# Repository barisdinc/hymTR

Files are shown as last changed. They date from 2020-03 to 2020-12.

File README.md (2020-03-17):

# hymTR
APRS Tracker
Arduino Uno ile calisan bir APRS tracker projesidir. 
Temel oalrak asagidaki ozelliklere sahiptir :
- Herhangibir arduino ile calisir
- Telsize hoparlor arayuzunden baglanir
- 4 bitlik bir Direnc iskelesi (resistor ladder) DAC ile calisir (16 seviye)
- Asagidaki verileri GPS den okur
  - Zaman
  - Pozisyon
  - Hiz/yonlenme vb
  - Uydu sayisi
  - Fix durumu
- Smart beacon ozelligi ile hiz ile orantili olarak gonderme sikligini degistirir
- Verileri EEPROM'da saklar
- PC Yazilimi ile tum ayarlari degistirilebilir

Eklenmesi planlanan ozellikler :
- APRS dinleme ozelligi
- Dorji radyolari yonetebilme ozelligi
- Display ekelenebilir

PC Yonetim arayuzu programi "hymTR Ayar Programi" ayri bir repository icindedir.

Donanim detaylari icin <A HREF="https://github.com/barisdinc/hymTR/blob/master/Hardware/README.md">Donanim Sayfasi'na bakabilirsiniz</A>

Ocak 2020

Proje destekcileri :
--------------------
- TA2GY Cem Karagoz
- TA6AEU Emre Keles

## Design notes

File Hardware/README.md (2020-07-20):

hymTRacker Donanim Genel gorunumu

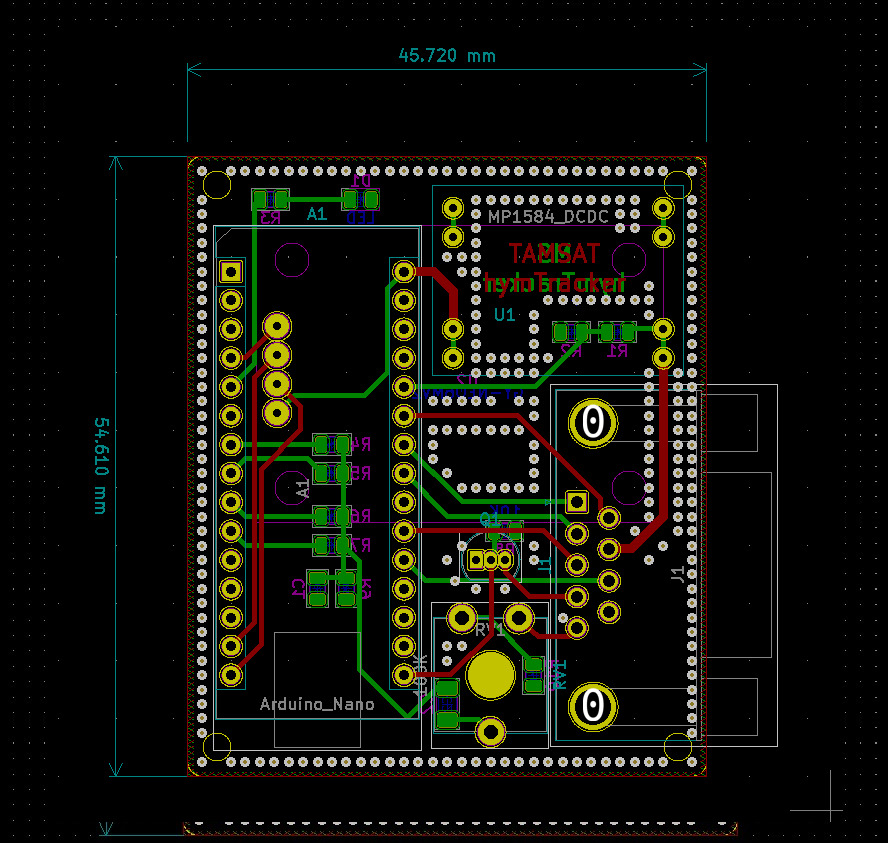
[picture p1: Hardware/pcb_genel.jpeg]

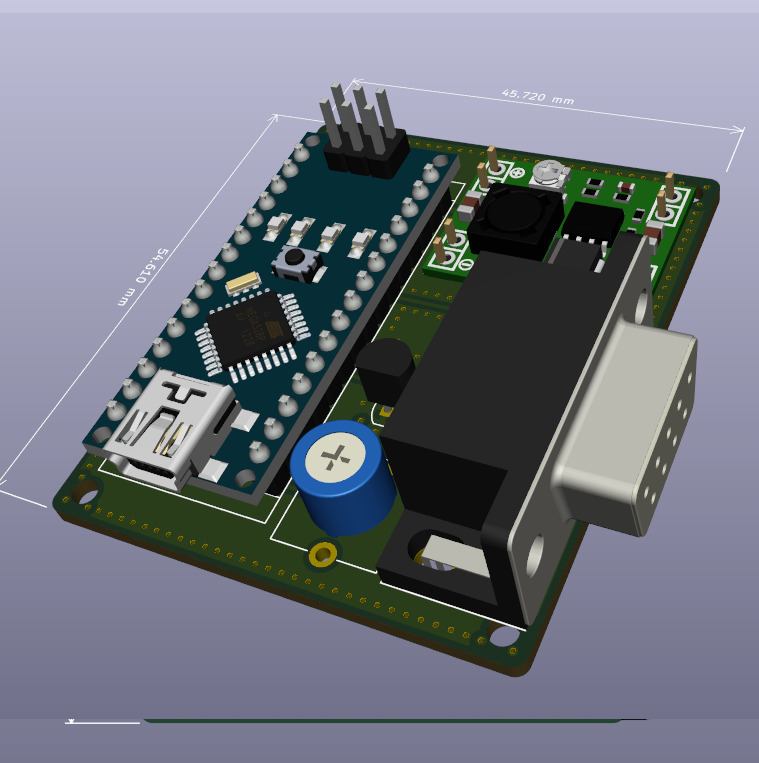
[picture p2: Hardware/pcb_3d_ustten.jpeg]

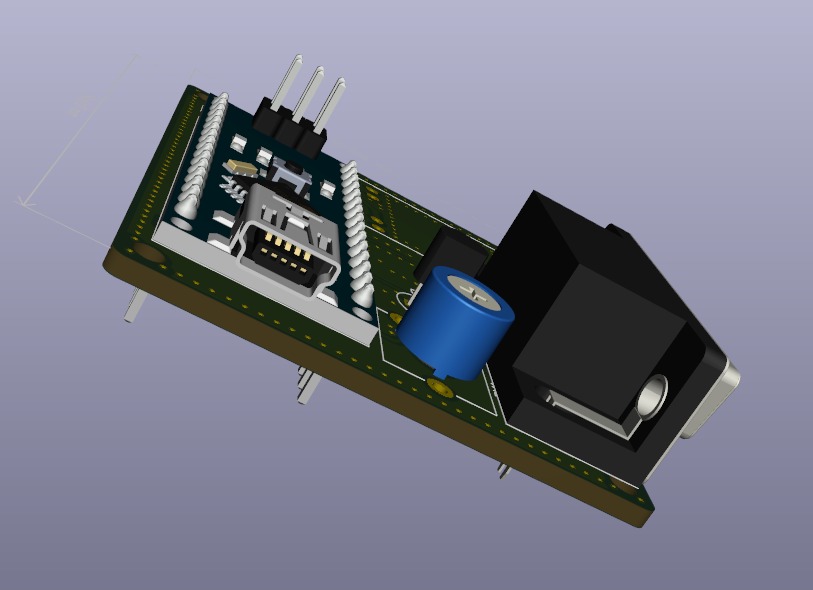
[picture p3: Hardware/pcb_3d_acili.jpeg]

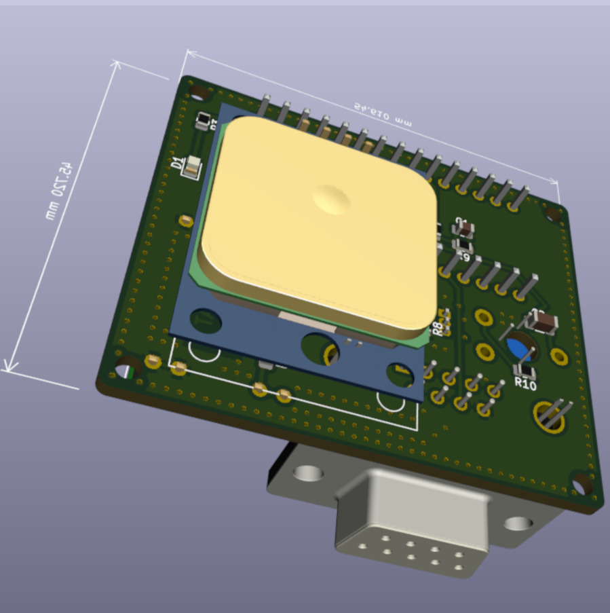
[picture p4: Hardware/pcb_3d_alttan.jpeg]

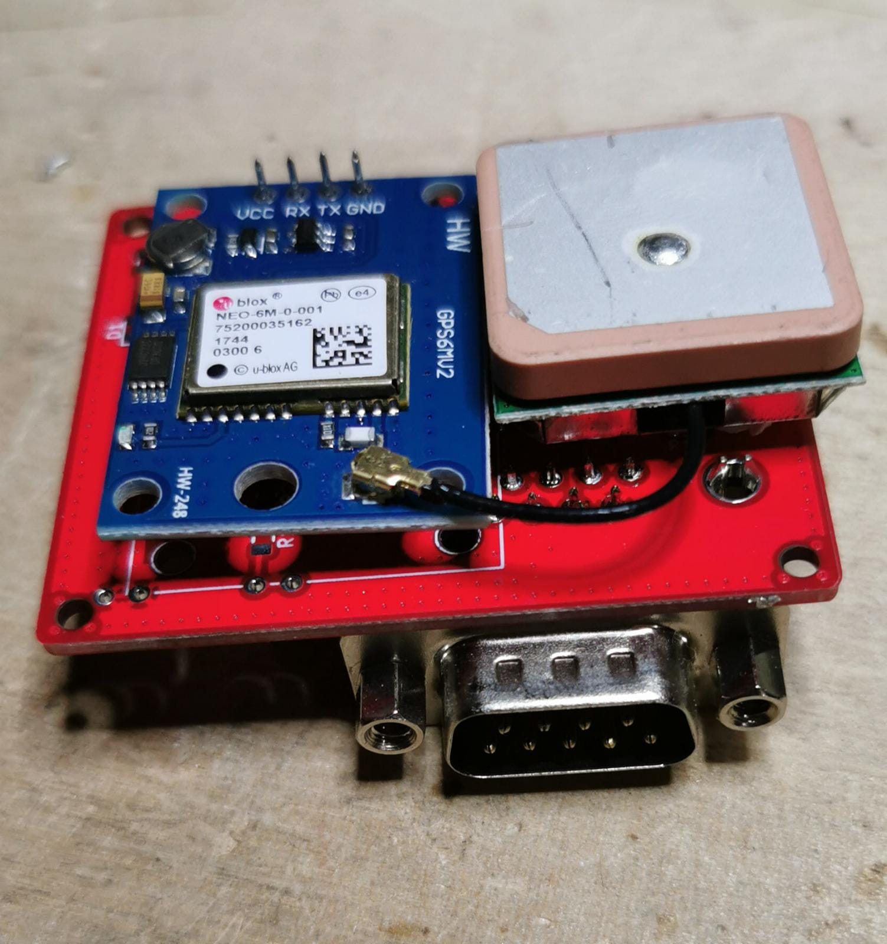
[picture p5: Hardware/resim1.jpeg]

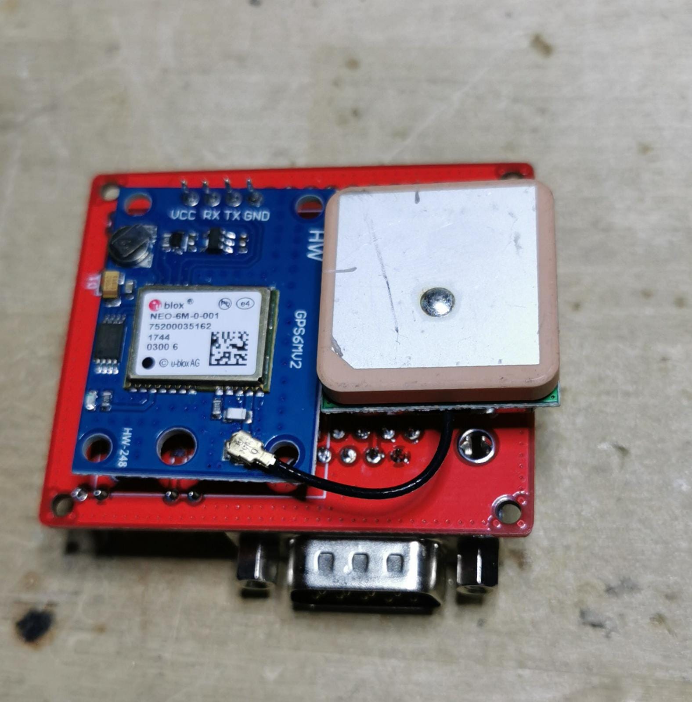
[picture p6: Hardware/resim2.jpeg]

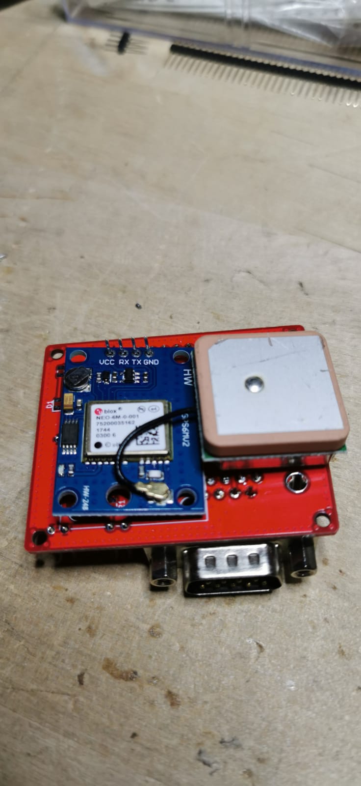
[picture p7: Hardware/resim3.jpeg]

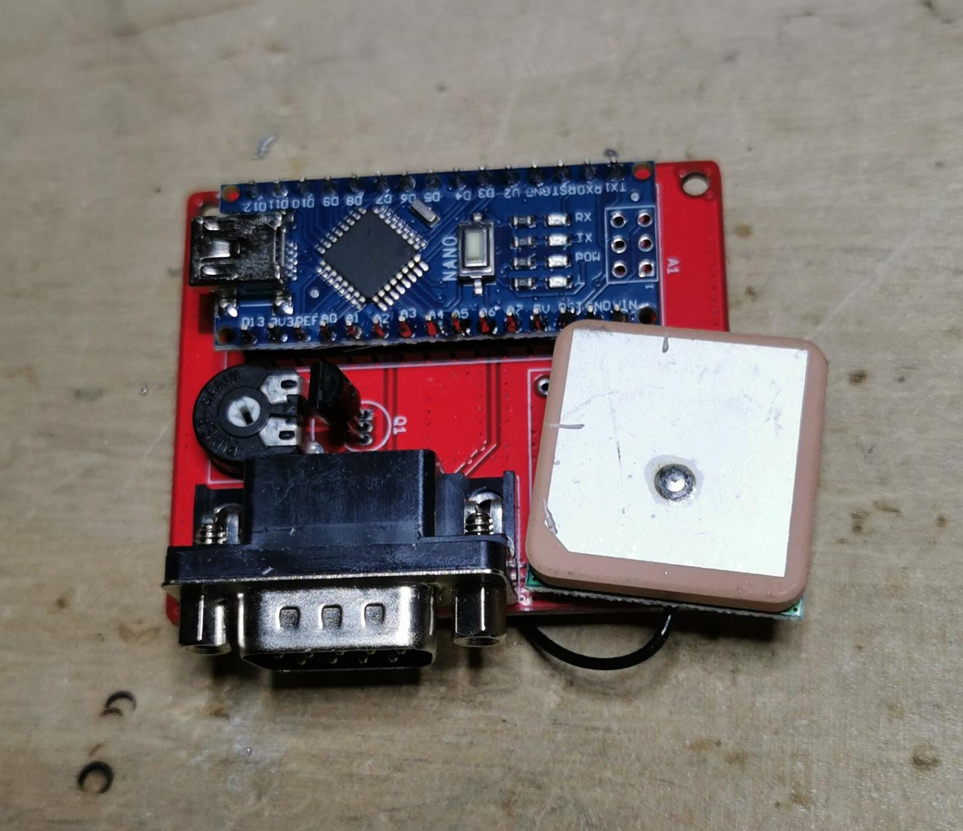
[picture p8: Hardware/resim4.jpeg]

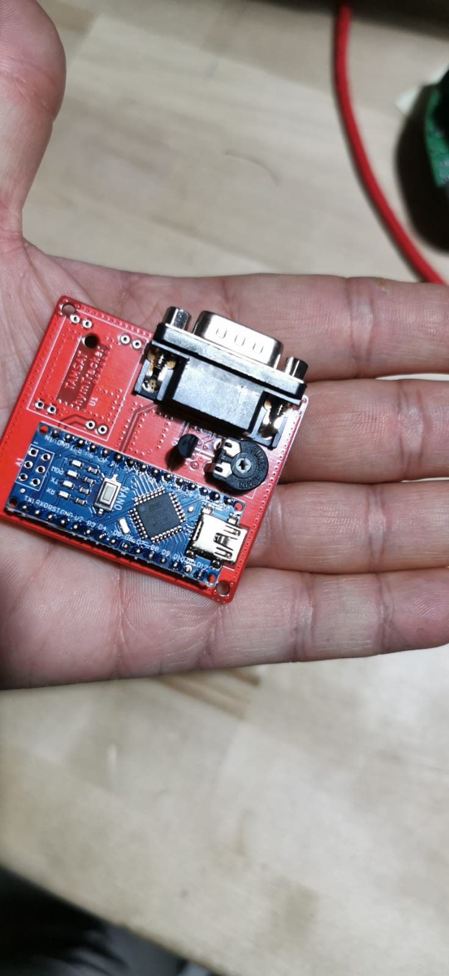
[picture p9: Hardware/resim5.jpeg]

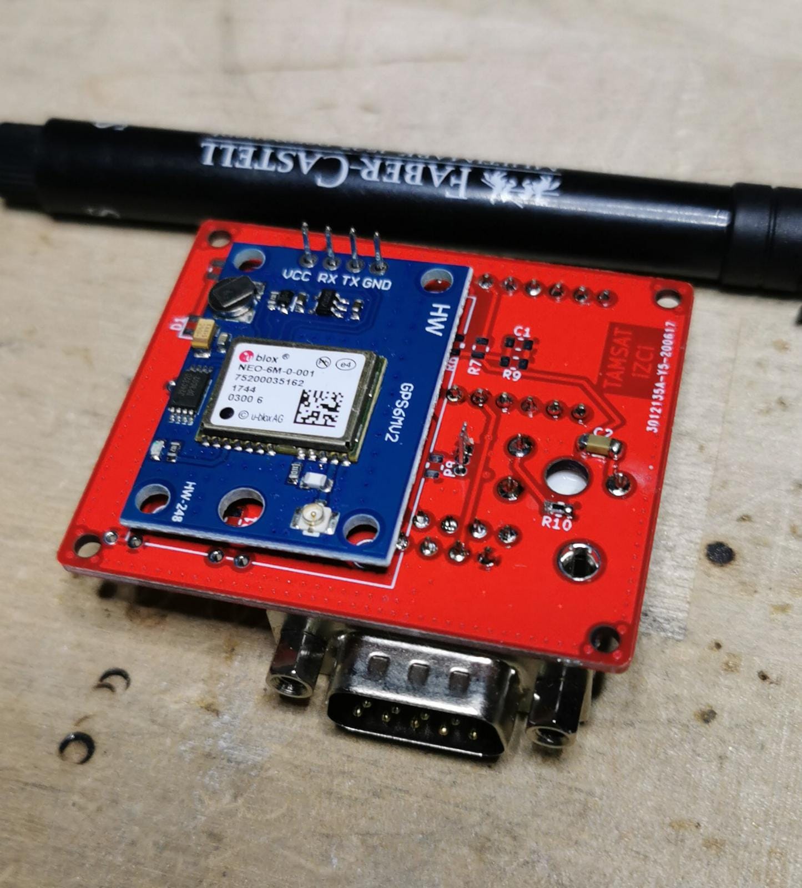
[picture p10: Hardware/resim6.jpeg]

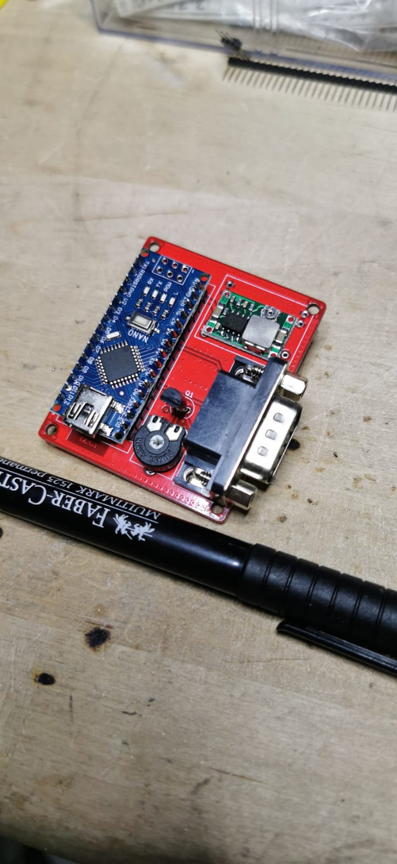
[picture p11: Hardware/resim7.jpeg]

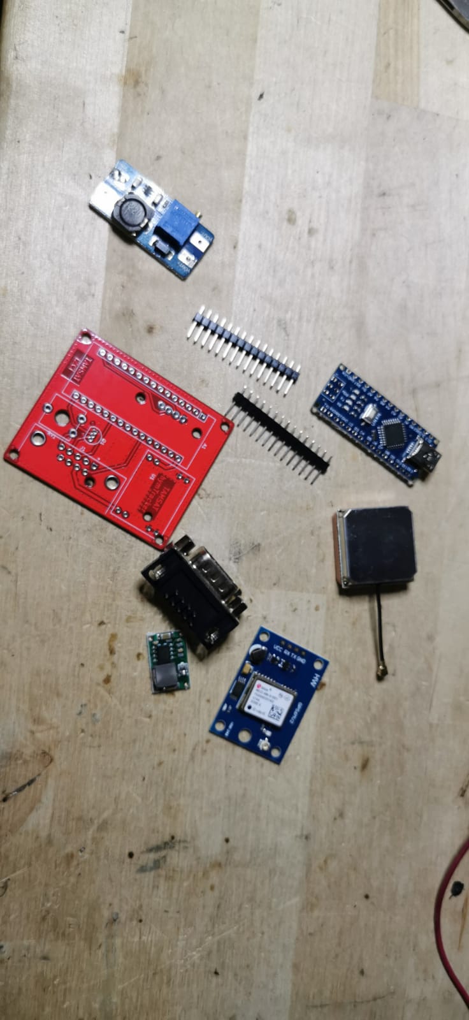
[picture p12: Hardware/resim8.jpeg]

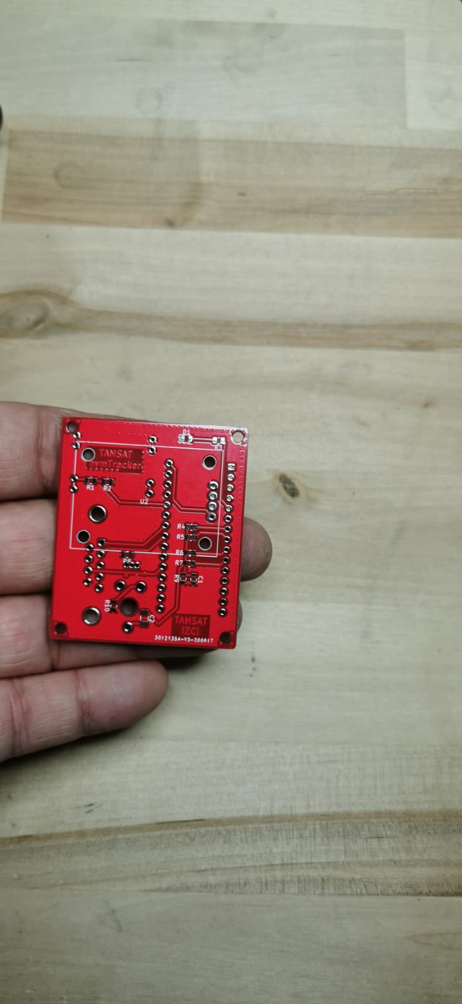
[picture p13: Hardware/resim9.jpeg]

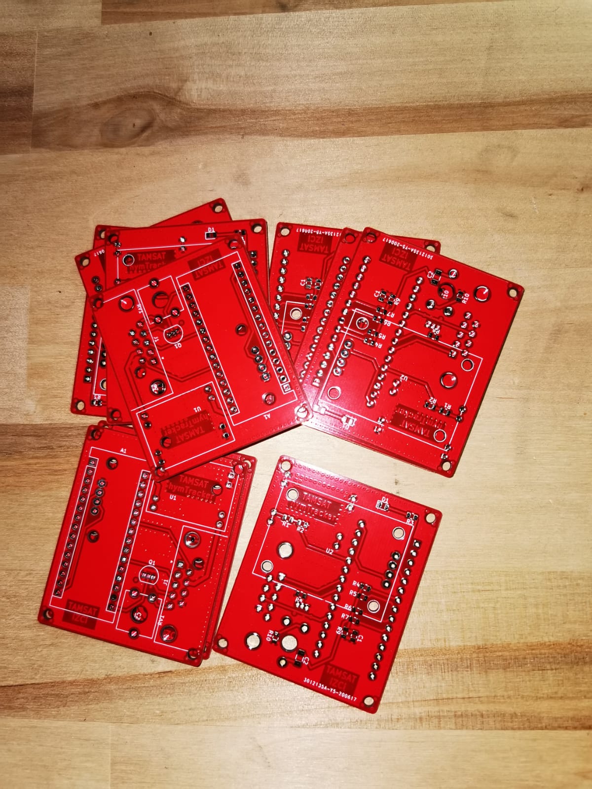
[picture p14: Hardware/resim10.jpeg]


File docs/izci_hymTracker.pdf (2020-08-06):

Önce biraz tarihte yolculuk yapalım….
Yıllar yıllar önce telsiz üzerinden bilgisayar verisi gönderebileceğimi keşfettiğimde dünyalar benim olmuştu. 90’lı yıllarda telsizlerimize bağladığımız ANTRAK HF/VHF modemleri ile hem HF’de (300 baud) hem de VHF’de (1200 baud) pekçok sayısal haberleşmeyi başarmıştık. Yavaştı ama çok da iş görüyordu.
90’lı yıllarda ülkemize henüz internet yeni gelmişken ve kimseciklerin evinde internet yokken, hatta adını bile kimse bilmezken biz bir grup amatör telsizci (ki ben evime telefon bağlatamadığım ve telefon sırasının da 6 aydan önce olmamacı da abir yana) telsizlerimize bağladığımız modemler ve AX25 protokolü ile birbirimizle haberleşiyorduk.
Uzun bir süre ÖDTÜ ve Ankara Üniversitesime kurduğumuz AMPR (Amateur Packet Radio Network) üzerinden internete de bağlanıyorduk.
Bu konular ve o yıllardaki deneyimlerimizle ilgili olarak şu linkleri ziyaret etmenizi öneririm ;
- Telsiz Veri İletişimi (Bölüm 1) : https://www.youtube.com/watch?v=VK49hlQoCso
- Telsiz Veri İletişimi (Bölüm 2) : https://www.youtube.com/watch?v=RfGFjVR-Ls0&t=9s
- Telsiz Veri İletişimi Sunum Dokümanı : https://github.com/barisdinc/Sunumlar/raw/master/ANTRAK_AX25_APRS_v1.pdf
- Linux ve AX25 : https://github.com/barisdinc/Sunumlar/raw/master/Packet-Radio-ve-Linux %20(2).ppt (https://github.com/barisdinc/Sunumlar/raw/master/Packet-Radio-ve-Linux%20(2).ppt)

Ardından internetin yaygınlaşması, her eve kolayca telefon (dialup) ve dahası ADSL, WIFI gibi hizmetlerin gelmesi, cep telefonlarındaki akıl almaz ilerleme sonrasında bu telsiz üzerinden veri haberleşmesi konusuna biraz uzak kalmıştım.
Taa ki askeri bir projede kullanabileceğim bir altlık protokolü arayışına girene dek, eski dost yine beni kurtarmıştı “AX25”…. Gerçi küp uydu haberleşme sistemlerinde AX25 ile haşır neşir oluyorduk ama temel kullanımdan öteye de geçemiyorduk.
Dokümanları okurken, hep bildiğim ucundan kullandığım ama bir yandan da kendimce “ARAÇ TAKİP SİSTEMİ” muamelesi çektiğim APRS (Amateur Paclet Reporting System) sistemini inceleyince gördüm ki zamanında (1980’li yıllar) askeri gemilerin haberleşmesi ve hem koordinat paylaşımı hem de taktik deniz resmi oluşturulması için bu protokolün içinde yok yok. O zamanlar bunu Commodore 64 bilgisayar üzerinde çalıştırıyor ve gemi telsizlerine bağlayarak kullanıyorlarmış.
APRS ile ilgili olarak spesifikasyonların anlatıldığı http://www.aprs.org/doc/APRS101.PDF dokümanı okuyabileceğiniz en güzel doküman bence.

Nasıl başladık…….
Bu arada bir Amatör Telsizci APRS grubu olan “APRS Türkiye” grubuna dahil olmuştum ve Türkiye’deki APRS çalışmalarını uzaktan takip etmeye çalışıyordum. Birgün bu platformun yöneticilerinden Emre Keleş (TA6AEU) ile yaptığımız uzun bir telefon görüşmesinde “biz bir tracker yapamazmıyız?” sorusu herşeyin başlangıcı oldu. Yaparız yapmasına da, öyle herhangibir tracker yapmak bize yakışmazdı, o yüzden hemen “yaparız” demedim, kafamın içinde uzun vadeli bir plan yaptım (bu görüşme sanırım 1 yıl kadar önceydi).

Önce yapılmış olan projeleri incelemeye başladım, sonra nasıl bir donanım olmalı konusuna yoğunlaştım. Hem basit olmalıydı, herkes kolayca yapabilmeli ve kullanabilmeliydi hem de biz eözgün olmalıydı.

Örnekleri inceleyince gördüm ki donanımda özgünlüğü sağlamak zor olacaktı,;
- Herkesin kolayca erişebileceği ve programlayabileceği bir arduino
- En ucuzundan bir GPS alıcısı
- Basit bir regülatör yada buck çevirici
- Konnektörler ve ledler

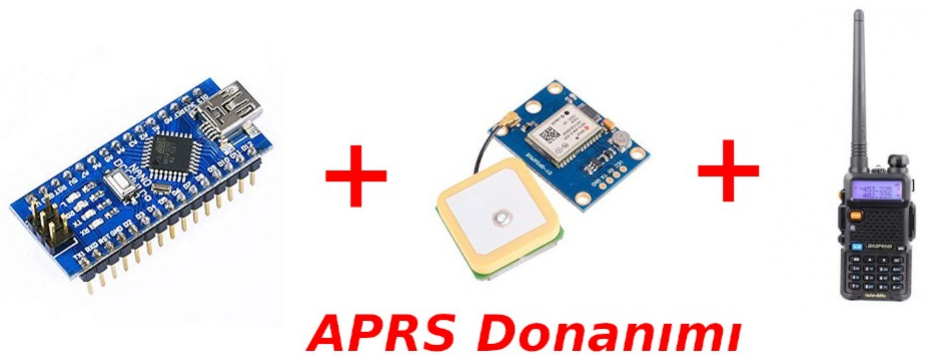
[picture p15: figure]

Ama yazılım konusunda özgün birşeyler oluşturabilirdik. İşte böyle başladı “İZCİ hymTracker” projesi.

Nasıl oluyor da oluyor…..
Sanırım kolay olan tarafı donanım olacağı için donanımdan başlamak daha doğru olacak. Amacımız 1200 ve 2200 Hz’lik ses tonları üretmek ve bunlara ‘0’ ile ‘1’ sayısal değerlerini eşlemek (bunlara mark ve space de denir). Yani işlemcimizden (arduino Nano için ATMEL mega328p) çıkacak veriyi 2 tondaki ses sinyallerine çevirmeliyiz.

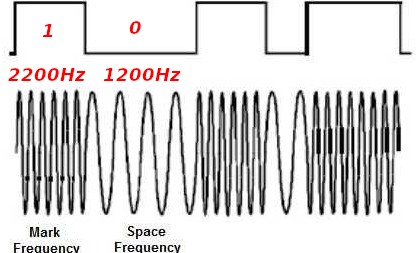
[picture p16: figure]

Sayısal verinin analog bir forma dönüştürülmesine Analog-to-Digital Conversion (ADC) diyoruz ve bunu ya bir ADC çipi ile ya da en basinten Resistor-Ladder dediğimiz birkaç direnç ile yapabiliyoruz. En ucuz ve kolay yolu (işlemcimizde de yeterince boş bacağımız olduğu için) resistor ladder (direnç merdiveni) olduğundan 4-bit’lik (4 tane işlemci sayısal bacağı kullanan) devreyi kullanmayı tercih ettim.

Aşağıda şemamızın bu bölümünü görebilirsiniz;

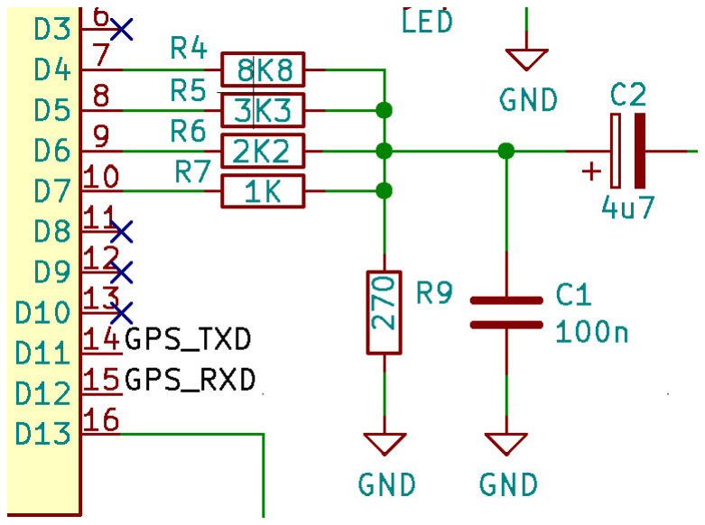
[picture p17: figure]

İşlemcimizin D4,D5,D6 ve D7 bacaklarından HIGH (3V3) verdiğimizde hesaplanmış olan dirençler üzerinden toplanarak (1K, 2K2, 3K3 ve 8K8) bir voltaş değeri oluşturulur. Bu işlemci kontrolünde çok hızlı yapabilirisek (1200 Hz için saniyede yaklaşık 1200 kez ve 2200 Hz için saniyede 2200 kez, ya da yazının yazılım bölümünde anlatacağım küçük bir trik ile daha basit bir şekilde) 4 bitlik yani 14 seviyeye sahip bir sayısal analog çevirici yapmış oluruz. Oluşan sinyal aşağıdakine benzer birşey olacaktır;

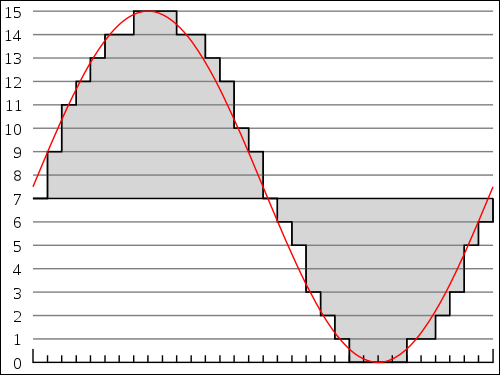
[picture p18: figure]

Aslında APRS Tracker’ımızın en can alıcı noktası yani modemi de sadece bu 4 dirençten oluşuyor. Kalan kısmında 2 bacak üzerinden (RX ve TX) bağlı olan GPS’imiz, PTT tetiklemesi için bir transistörümüz, TX anında yanan bir LED2imi, 9 pin DSUB-9 konnektörümüz ve sistemin 3-30 volt aralığında çalışmasını sağlayan BUCK converterimiz var. BU sayede sistem aşağıdaki gibi beslemelerle hiçbir değişiklik ya da düzenleme yapılmaksızın kullanılabiliniyor;
- Sistem 3V7 lityum pil
- 5V power bank
- 9V kare pil
- 12V araba aküsü
- 19V laptop pili
- 24V kamyon aküsü, vb.
Şemamız aşağıdaki gibidir;

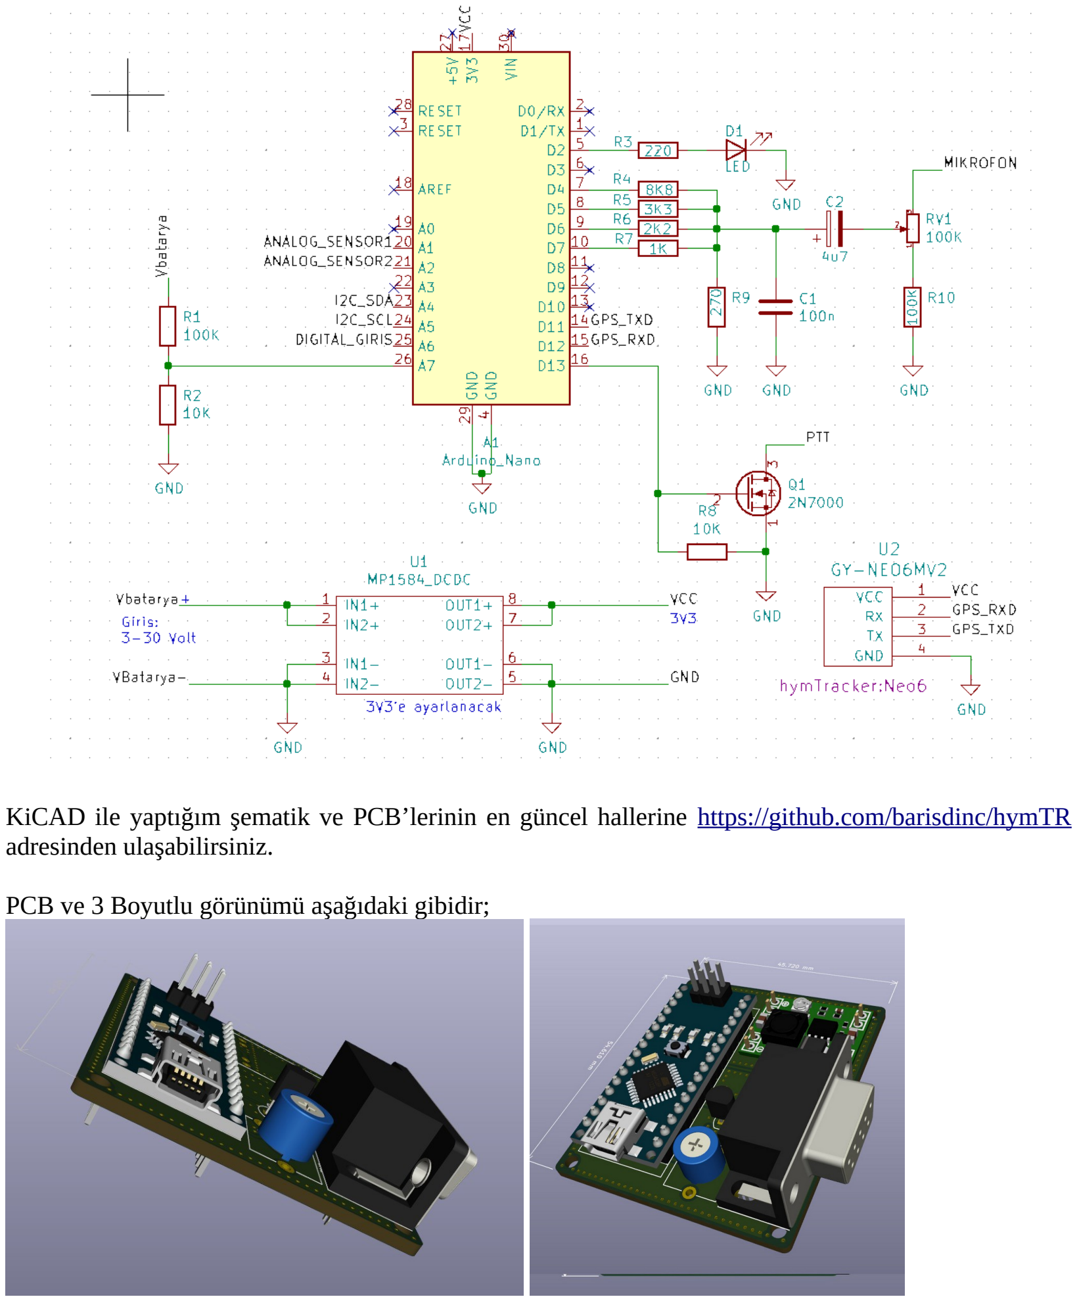
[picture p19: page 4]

KiCAD ile yaptığım şematik ve PCB’lerinin en güncel hallerine https://github.com/barisdinc/hymTR adresinden ulaşabilirsiniz.

PCB ve 3 Boyutlu görünümü aşağıdaki gibidir;

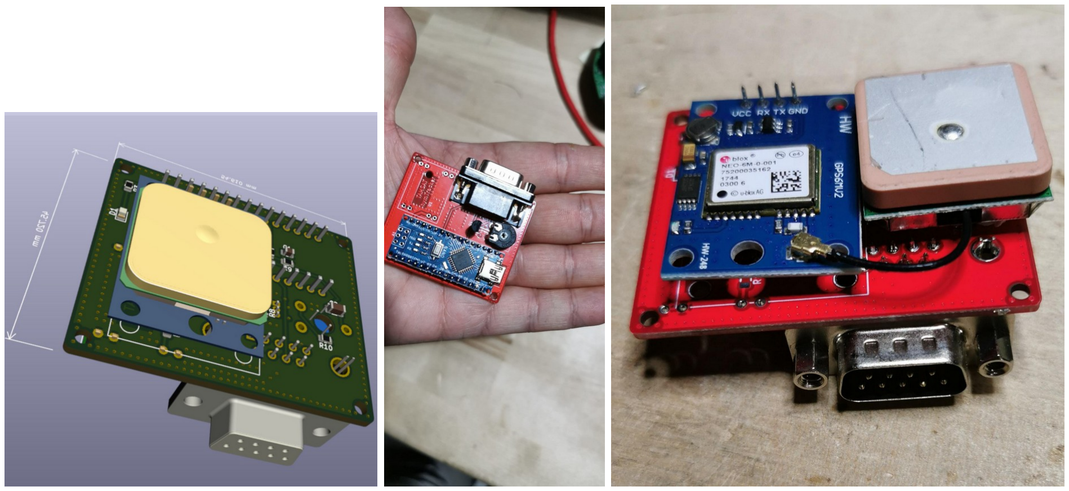
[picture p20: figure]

Donanım istediğimiz boyutlarda ve özelliklerde, küçük bir kutu içerisinde aracımızın herhangi bir yerine koyabiliriz.

Peki ya işlemci üzerindeki yazılım !!!!….

İşlemci üzerindeki yazılım yapması gerekenleri şu şekilde belirlemiştim;
- 1200Hz ve 2200Hz sinyallerini direnç-merdiveni DAC devresini kullanarak oluşturacak,
- AX25 dizilimine uygun olarak APRS paketleri oluşturabilecek,
- GPS den koordinat ve zaman bilgisi okuyabilecek,
- GPS verisini APRS verisine çevirebilecek,
- Batarya/Akü durumunu ölçebilecek ve bunu APRS verisine ekleyebilecek,
- Harici sensörlerden (analog ve sayısal) verş okuyarak bunları APRS verisine ekleyebilecek
https://github.com/barisdinc/hymTR/blob/master/src/hymTR.ino | adresinden | erişebileceiğiniz
programın genel özellikleri aşağıdaki gibi açıklanabilir;

LibAPRS_Tracker kütüphanesini kullanır. Bu kütüphane bu proje kapsamında hazırlanmış ve Arduino IDE kütüphanesi olarak kaydettirilmiş bir kütüphane olup, Ardu,ino IDE’sindeki (bugün için) tek
APRS | Tracker | kütüphanesidir | (https://www.arduinolibraries.info/libraries/lib-aprs_tracker,
https://github.com/barisdinc/LibAPRS_Tracker,https://platformio.org/lib/show/7001/LibAPRS_Tracker)

Kütüphanenin görevi AX25 paketini oluşturmak ve APRS için gerekli ses sinyallerini üretmektir. Bu kütüphaneyi kullanarak ve sadece birkaç satır kod yazarak aşağıdaki gibi bir APRS programı çalıştırabilirsiniz;

/*
* This is a very simple usage for LibAPRS_Tracker
*
* Author : Baris DINC (TA7W/OH2UDS)
*
*/
#include <LibAPRS_Tracker.h>

void setup()
{
APRS_init();
char myCALL[] = "TA7W";
char Lat[] = "2134.00N";
char Lon[] = "01234.00E";
APRS_setCallsign(myCALL, 9); APRS_setLat(Lat);
APRS_setLon(Lon);
}
void loop() {
char comment []= "TAMSAT hymTR APRS Tracker Test"; APRS_sendLoc(comment, strlen(comment));
while(bitRead(PORTB,5)); //Wait for transmission to be completed delay(10000); }

Bunun ayarlarını nasıl yapacağız ?….

Herkesin arduino programını açıp çağrı işaretini değiştirmesini ya da sembolünü ayarlamasını bekleyemezdik bu nedenle bir de PC programı yazdık ayarları kolayca yapılabilsin diye. Ben M$ windows ortamına sahip olmadığım ve genelde Linux kullandığım için programı multiplatform (yani her işletim sisteminde çalışabilen) bir program yapmayı hedefledik.
APRS Tracker’imizin tüm ayarlarını yapabileceğimiz aşağıdaki gibiprogram oluşmuş oldu. BU programla tracker içindeki bilgileri bilgisayara yükleyebiliyor, bilgisayar ekranında yaptığınız ayarlamaları da kolayca tracker’in hafızasına yükleyebiliyorsunuz.

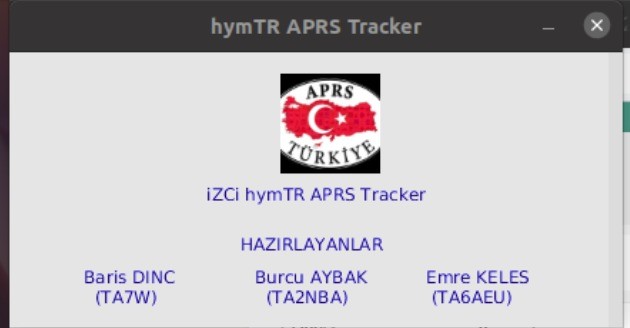
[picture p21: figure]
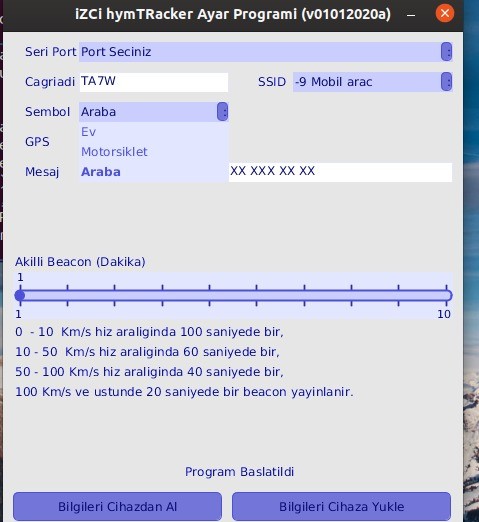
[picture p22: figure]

Başta bu çalışmanın gerçeklenmesi için bizleri yüreklendiren arkadaşlarımız olmak üzere, bu projeyi gerçekleştirecek ve kullanacak herkese yapacakları geridönüşler ve iyileştirmeler için şimdiden teşekkür etmek isterim.

Bu proje Türk Amatörlüğü’nü bir adım daha ileri götürmek, APRS çalışmalarının ülkemizde de olabildiğince yaygınlaşmasını sağlamak amacı ile bu amaçla gönüllü olarak çalışan APRS Türkiye grubunun çalışmalarına az da olsa katkıda bulunmak amacı ile hazırlanmıştır.
Bu proje devamında, aynı veya benzer kütüphane altlığımızı kullanarak (gerekiyor ise daha da geliştirerek);
- Digipeater
- Gateway
- APRS Telsiz
gibi çalışmaları ekibimize katılacak gönüllü dostlarımızla gerçekleştirmeyi hedefliyoruz.

Barış DİNÇ
TA7W / OH2UDS

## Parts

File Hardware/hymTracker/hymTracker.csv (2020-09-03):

Id | Designator | Package | Quantity | Designation | Supplier and ref
1 | C1 | C_1206_3216Metric | 1 | 100n
2 | D1 | LED_1206_3216Metric | 1 | LED
3 | R10,R1 | R_1206_3216Metric | 2 | 100K
4 | R9 | R_1206_3216Metric | 1 | 270
5 | R8,R2 | R_1206_3216Metric | 2 | 10K
6 | R7 | R_1206_3216Metric | 1 | 1K
7 | R6 | R_1206_3216Metric | 1 | 2K2
8 | R5 | R_1206_3216Metric | 1 | 3K3
9 | R4 | R_1206_3216Metric | 1 | 8K8
10 | R3 | R_1206_3216Metric | 1 | 220
11 | RV1 | Potentiometer_ACP_CA9-V10_Vertical_Hole | 1 | 100K
12 | U2 | Neo6 | 1 | GY-NEO6MV2
13 | U1 | MP1854EN_board | 1 | MP1584_DCDC
14 | Q1 | TO-92_Inline | 1 | 2N7000
15 | J1 | DSUB-9_Female_Horizontal_P2.77x2.84mm_EdgePinOffset7.70mm_Housed_MountingHolesOffset9.12mm | 1 | DB9_Female
16 | C2 | C_1206_3216Metric | 1 | 4u7
17 | A1 | Arduino_Nano | 1 | Arduino_Nano

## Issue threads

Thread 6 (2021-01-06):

Tes button

barisdinc, 2021-01-06:
Sistemin calisip calismadigini test etmek icin bir test butonu koyulabilir, bu butopna basildiginda hazirdaki bir paket (var ise GPS datasi ile yok ise bos olarak) bir paket gonderimi saglanmalidir

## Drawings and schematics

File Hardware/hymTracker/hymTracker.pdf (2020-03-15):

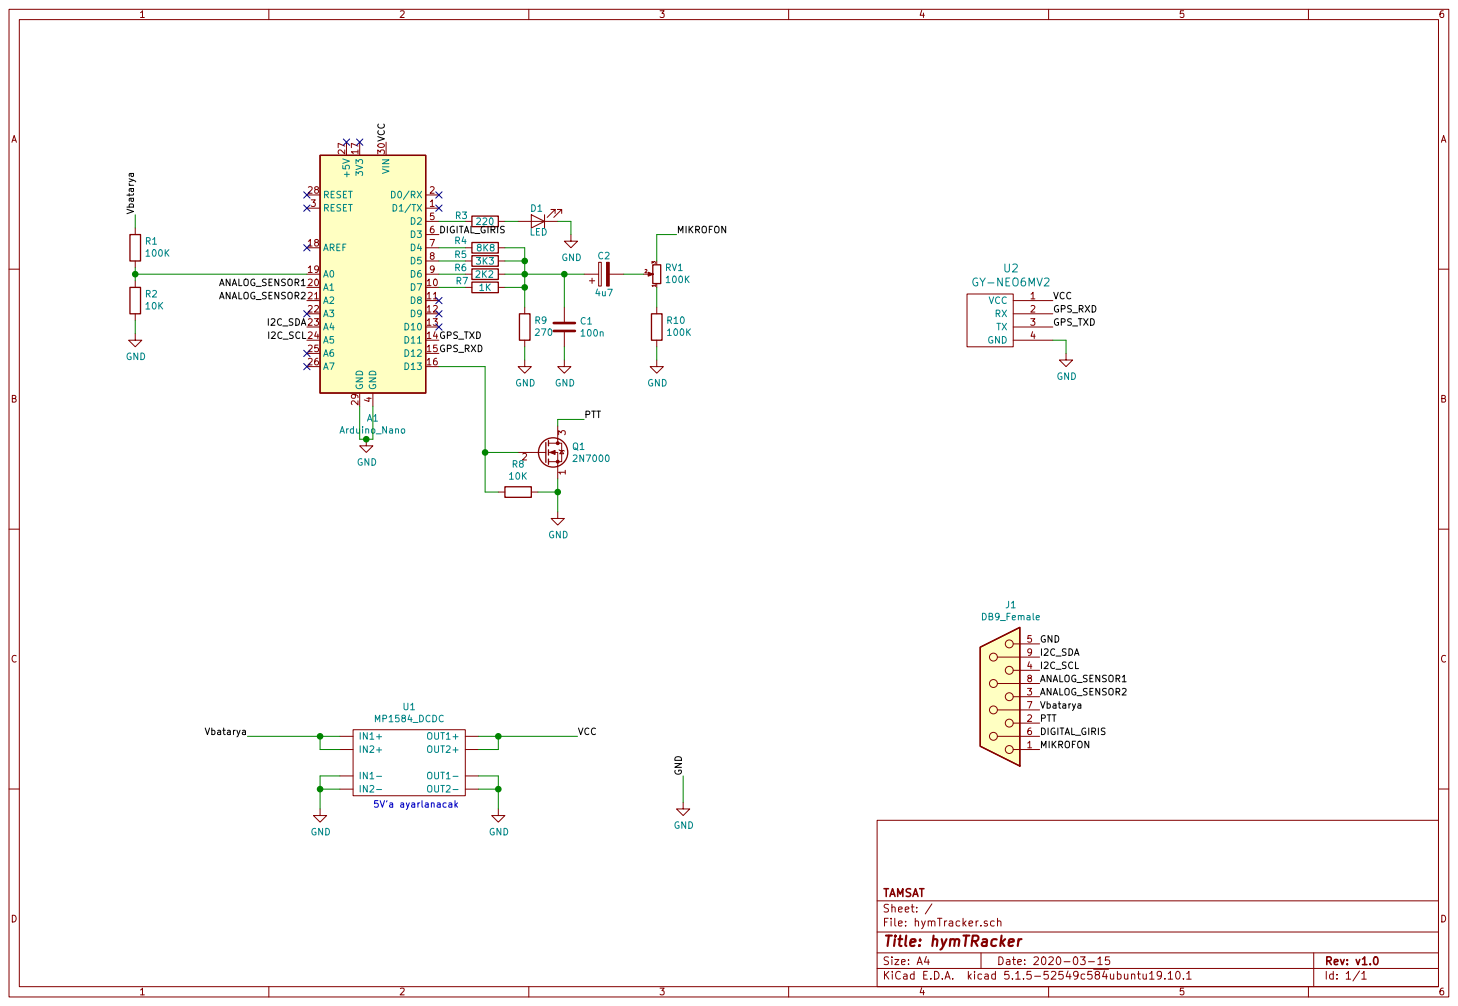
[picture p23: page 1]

File: hymTracker.sch Sheet: / TAMSAT

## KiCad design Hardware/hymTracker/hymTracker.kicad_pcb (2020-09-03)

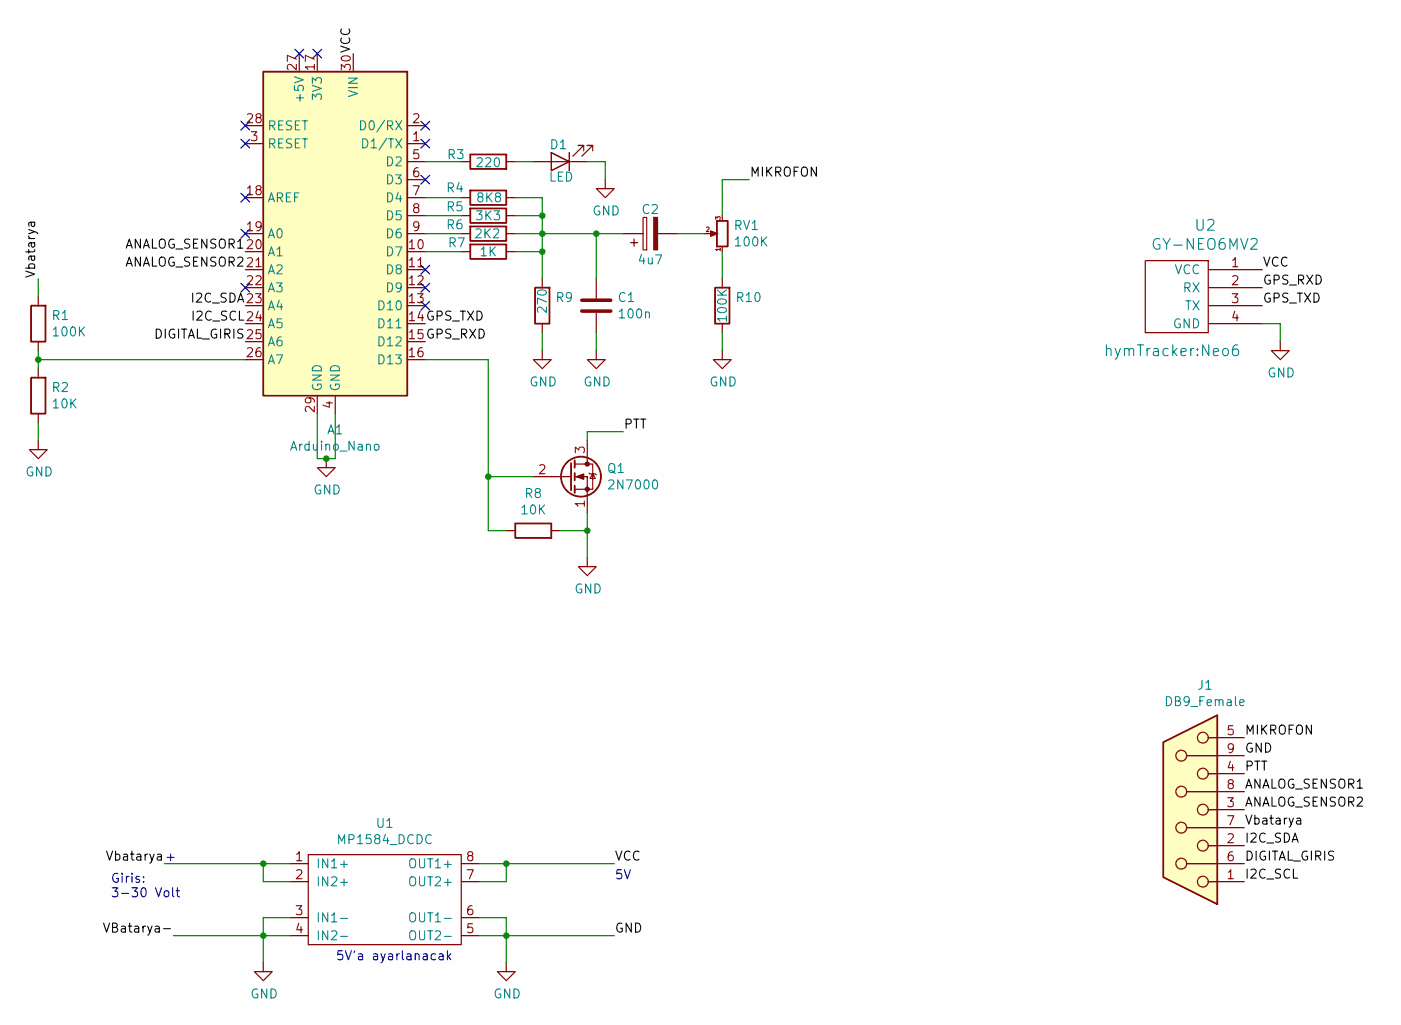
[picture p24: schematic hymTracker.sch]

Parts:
A1: Arduino_Nano
C1: 100n; C_0805_2012Metric
C2: 4u7; C_1206_3216Metric
D1: LED; LED_0805_2012Metric
J1: DB9_Female; DSUB-9_Female_Horizontal_P2.77x2.84mm_EdgePinOffset7.70mm_H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
Q1: 2N7000; TO-92_Inline
R1, R10: 100K; R_0805_2012Metric
R2, R8: 10K; R_0805_2012Metric
R3: 220; R_0805_2012Metric
R4: 8K8; R_0805_2012Metric
R5: 3K3; R_0805_2012Metric
R6: 2K2; R_0805_2012Metric
R7: 1K; R_0805_2012Metric
R9: 270; R_0805_2012Metric
RV1: 100K; Potentiometer_ACP_CA9-V10_Vertical_Hole
U1: MP1584_DCDC; MP1854EN_board
U2: GY-NEO6MV2; Neo6

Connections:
/ANALOG_SENSOR1: A1.20 (A1), J1.8
/ANALOG_SENSOR2: A1.21 (A2), J1.3
/DIGITAL_GIRIS: A1.25 (A6), J1.6
/GPS_RXD: A1.15 (D12), U2.2 (RX)
/GPS_TXD: A1.14 (D11), U2.3 (TX)
/I2C_SCL: A1.24 (A5), J1.1
/I2C_SDA: A1.23 (A4), J1.2
/MIKROFON: J1.5, RV1.3
/PTT: J1.4, Q1.3 (D)
/VCC: A1.30 (VIN), U1.7 (OUT2+), U1.8 (OUT1+), U2.1 (VCC)
/Vbatarya: J1.7, R1.2, U1.1 (IN1+), U1.2 (IN2+)
GND: A1.4 (GND), A1.29 (GND), C1.2, D1.1 (K), J1.9, Q1.1 (S), R2.1, R8.2, R9.1, R10.1, U1.3 (IN1-), U1.4 (IN2-), U1.5 (OUT2-), U1.6 (OUT1-), U2.4 (GND)
unnamed: A1.5 (D2), R3.1
unnamed: A1.7 (D4), R4.2
unnamed: A1.8 (D5), R5.2
unnamed: A1.9 (D6), R6.2
unnamed: A1.10 (D7), R7.2
unnamed: A1.16 (D13), Q1.2 (G), R8.1
unnamed: A1.26 (A7), R1.1, R2.2
unnamed: C1.1, C2.1, R4.1, R5.1, R6.1, R7.1, R9.2
unnamed: C2.2, RV1.2
unnamed: D1.2 (A), R3.2
unnamed: R10.2, RV1.1

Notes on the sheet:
5V'a ayarlanacak
Giris: 3-30 Volt

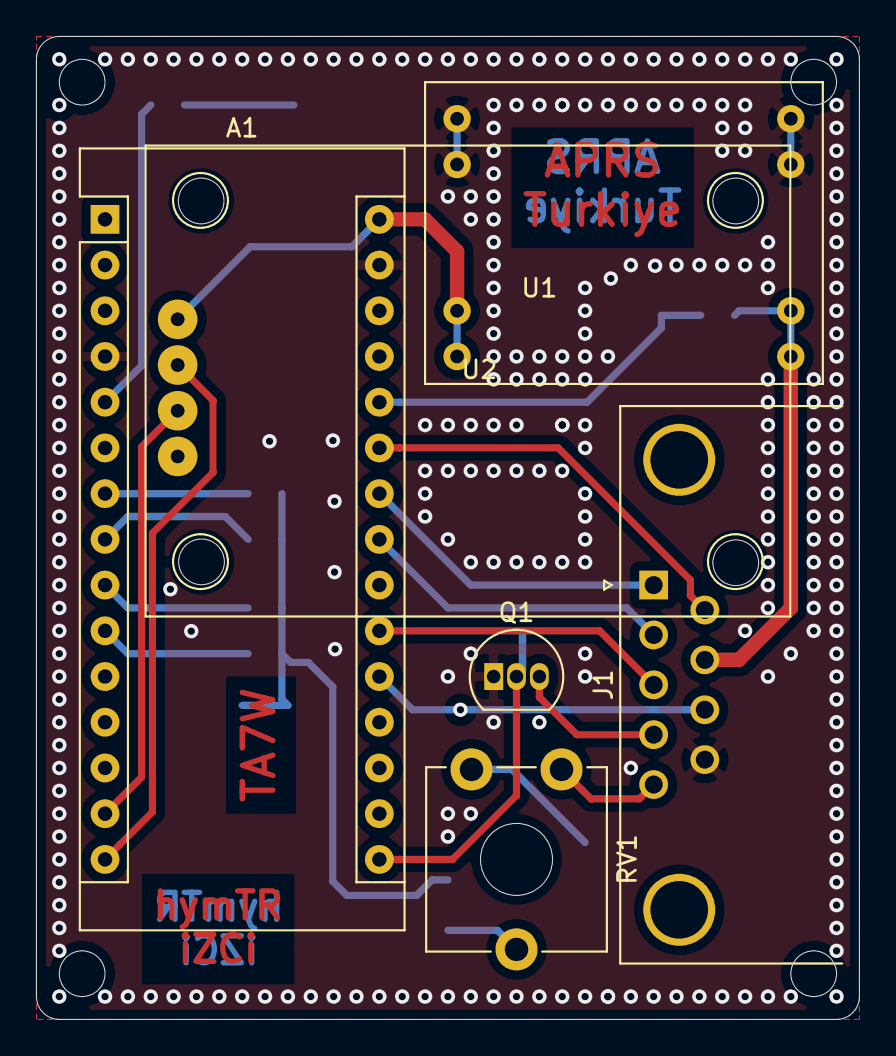
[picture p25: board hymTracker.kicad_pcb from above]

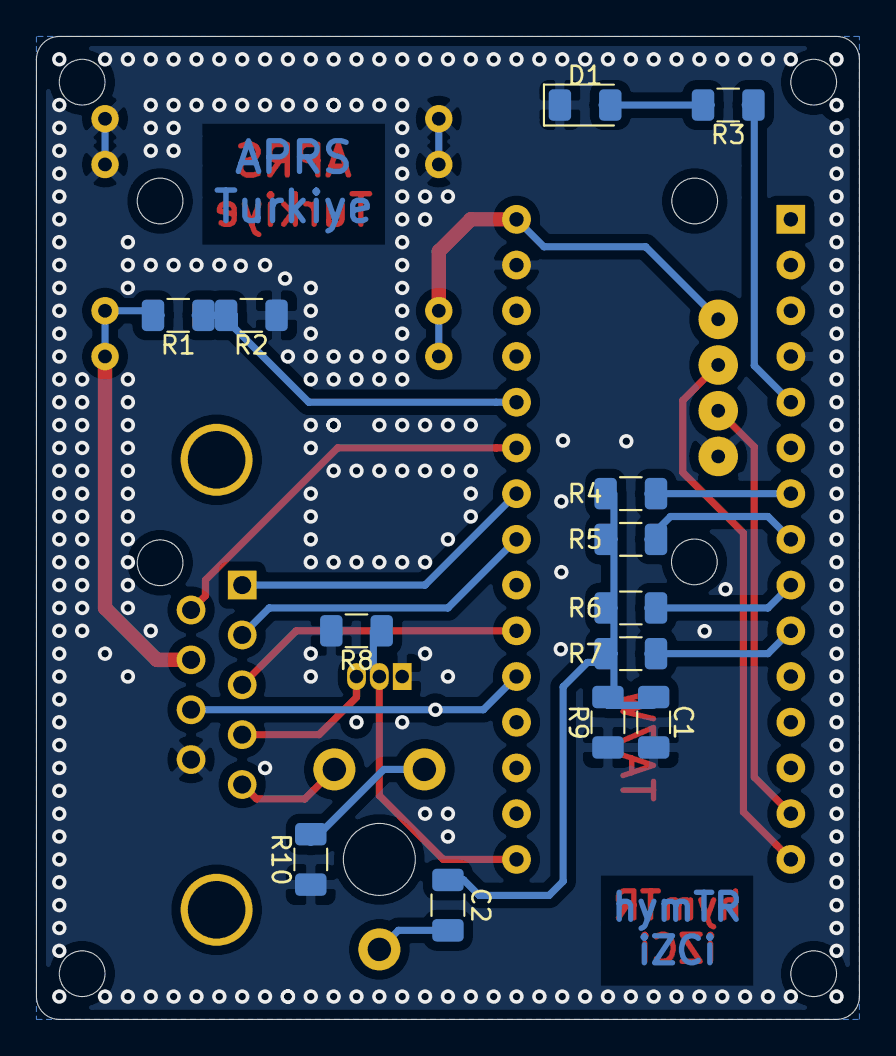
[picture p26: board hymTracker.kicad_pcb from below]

Board: 2 copper layers, 45.7 x 54.6 mm, 19 parts (13 on the bottom side), 23 nets.

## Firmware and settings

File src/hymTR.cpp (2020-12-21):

/*
 * hymTR 2020
 * Baris DINC - TA7W
 * 10 Ocak 2020
 * APRS Tracker
 */
//Pin tanimlamalari kutuphane include larindan once yapilmalidir.
#define RX_PIN 11  //GPS TX pin 
#define TX_PIN 12  //GPS RX pin

#include <Arduino.h>
#include <LibAPRS_Tracker.h>
#include <NMEAGPS.h>
#include <GPSport.h>
#include <EEPROM.h>

/*
 * Notlar:
 * NeoGPS kutuphanesinde su duzenlemeleri yapiniz;
 *  GPSport.h icinde #include <NeoSWSerial.h> satirini acip #include <AltSoftSerial.h> satirini kapatiniz
 *  NMEAGPS_cfg.h icinde NMEAGPS_INTERRUPT_PROCESSING define satirini acmaniz ya da burda tanimlamaniz gerekir
 */
#define NMEAGPS_INTERRUPT_PROCESSING

//Genel Tanimlamalar
#define VERSIYON "01012020a"

//Kutuphane kontrolleri
#if !defined(GPS_FIX_TIME) | !defined(GPS_FIX_DATE)
  #error NeoGPS kutuphanesinde GPSfix_cfg.h icinde  GPS_FIX_TIME ve DATE define edilmelidir
#endif
#if !defined(NMEAGPS_PARSE_RMC) & !defined(NMEAGPS_PARSE_ZDA)
  #error You must define NMEAGPS_PARSE_RMC or ZDA in NMEAGPS_cfg.h!
#endif

NMEAGPS  gps; // This parses the GPS characters
gps_fix  fix; // This holds on to the latest values
char comment []= "iZCi hymTR APRS Tracker Test";
#define CONV_BUF_SIZE 16
static char conv_buf[CONV_BUF_SIZE];

enum p_type {
  pt_normal,
  pt_phg,
  pt_cse,
  pt_dir
};

p_type curr_pt = pt_normal;

struct APRS_Ayarlari {
  char APRS_CagriIsareti[7];
  char APRS_CagriIsaretiSSID;
  char APRS_Destination[7];
  char APRS_DestinationSSID;  
  char APRS_Path1[7];
  char APRS_Path1SSID;
  char APRS_Path2[7];
  char APRS_Path2SSID;
  char APRS_Sembolu;
  char APRS_SembolTabi;
  byte APRS_BeaconTipi;    //0=sure beklemeli, 1=Smart Beacon
  unsigned long APRS_BeaconSuresi;
  unsigned int  APRS_GPSSeriHizi;    
  char APRS_Mesaj[41];
  boolean gps_varyok;
  char latitude[9];
  char longitude[9];
  char altitude[6];
  byte power;
  byte gain;
  byte height;
  byte directivity;
  unsigned int CheckSum;    //Cagri isaretinin byte toplamini kullaniyoruz
};
APRS_Ayarlari Ayarlar;

//forward declarations - fonksiyon tanimlarimiz
void KomutSatiriCalistir();
char* deg_to_nmea(float deg, boolean is_lat);
void eepromOku();
void eepromaYaz();
void VarsayilanAyarlar();
void konfigurasyonYazdir();
void parametreOku(char *szParam, int iMaxLen);
bool seridenAl();
void seriyeGonder();
void setPacket();
void sndPacket();
int getGpsData(boolean *newDataLoc);

static void GPSisr( uint8_t c )
{
  gps.handle( c );
} // GPSisr

void setup()
{
  eepromOku();
  APRS_init();
  //doReadPrams();
  //APRS_setCallsign(Ayarlar.APRS_CagriIsareti, Ayarlar.APRS_CagriIsaretiSSID);
  APRS_setPreamble(500); //TODO: read from settings
  APRS_setTail(50);      //TODO: read from settings

  DEBUG_PORT.begin(115200);
  while (!DEBUG_PORT);
  DEBUG_PORT.print( F("hymTR APRS Tracker\n") );
  gpsPort.attachInterrupt( GPSisr );
  gpsPort.begin(9600);
}


void loop()
{
  boolean newData = false;
  int smartBeaconInterval = 60;

  int gpsMinSec = getGpsData(&newData);
  //if (gps.available()) {
    // Print all the things!
    //trace_all( DEBUG_PORT, gps, gps.read() );
  //}

    if (gps.overrun()) {
    gps.overrun( false );
    DEBUG_PORT.println( F("DATA OVERRUN!") );
  }
  
  //Hiza gore Smart beacon suresi ayarlama
  if (newData) {
    if (fix.speed_kph() <= 10)                            smartBeaconInterval = Ayarlar.APRS_BeaconSuresi * 20 * 5;
    if (fix.speed_kph() > 10  and fix.speed_kph() <= 50)  smartBeaconInterval = Ayarlar.APRS_BeaconSuresi * 20 * 3;
    if (fix.speed_kph() > 50  and fix.speed_kph() <= 100) smartBeaconInterval = Ayarlar.APRS_BeaconSuresi * 20 * 2;
    if (fix.speed_kph() > 100)                            smartBeaconInterval = Ayarlar.APRS_BeaconSuresi * 20 * 1;
  }

//SMART BEACON zamanlaamasi yapmasini istemiyorsak alttaki satirda bir sure (saniye) belirtebiliriz
//  smartBeaconInterval = 20;
  if (newData && ((gpsMinSec % smartBeaconInterval) == 0))
  {
    newData = false;
    DEBUG_PORT.println("sending....");
    setPacket();
    sndPacket();
  }
  //DEBUG_PORT.print(".");

//TODO: bunu Interrupt a tasiyacagim
  /*
   * Burada seri porttan komutlari okuyoruz
   * TODO: bunu interrupt a tasimaliyiz
   */
  
  while (DEBUG_PORT.available())
  {
    char komut = DEBUG_PORT.read();
     if (komut == '!') {
      KomutSatiriCalistir();
      }
  }


}

void setPacket()
{
    //    APRS_setCallsign(Ayarlar.APRS_CagriIsareti, Ayarlar.APRS_CagriIsaretiSSID);
    char myCALL[7];// = "      ";
    char Lat[9];// = "        ";
    char Lon[] = "         ";
    snprintf(myCALL,sizeof(myCALL),"%s",Ayarlar.APRS_CagriIsareti);
    snprintf(Lat,sizeof(Lat),"%s",deg_to_nmea(fix.latitude(),true));
    snprintf(Lon,sizeof(Lon),"%s",deg_to_nmea(fix.longitude(),false));
    APRS_setSymbol(Ayarlar.APRS_Sembolu);
    APRS_setLat(Lat);
    APRS_setLon(Lon);
    APRS_setCallsign(myCALL,Ayarlar.APRS_CagriIsaretiSSID);
    APRS_setDestination(Ayarlar.APRS_Destination, Ayarlar.APRS_DestinationSSID);
    APRS_setPreamble(1000);
    APRS_setTail(50);
    APRS_setPower(1);
    APRS_setHeight(1);
    APRS_setGain(1);
    APRS_setDirectivity(1);
    int heading = (int)fix.heading();
    float speedf = fix.speed_kph();
    int speed = (int)speedf;
    APRS_setDirection(heading);
    APRS_setCourse(heading);
    APRS_setSpeed(speed);
}

void sndPacket()
{
    char commentS[40]="                                       ";
    snprintf(commentS,sizeof(commentS),"/A=%06d %s",(int)(fix.alt.whole*3.28),Ayarlar.APRS_Mesaj);
    // APRS_sendLoc 3rd parameter : ' ' no extension, 'p' PHG, 'c' CSE/SPD, 'd' DIR/SPD 
    if (curr_pt == pt_normal) APRS_sendLoc(commentS, strlen(commentS),' '); 
    if (curr_pt == pt_phg)    APRS_sendLoc(commentS, strlen(commentS),'p'); 
    if (curr_pt == pt_cse)    APRS_sendLoc(commentS, strlen(commentS),'c'); 
    if (curr_pt == pt_dir)    APRS_sendLoc(commentS, strlen(commentS),'d'); 
    if (curr_pt == pt_normal)   curr_pt = pt_phg;
    else if (curr_pt == pt_phg) curr_pt = pt_cse;
    else if (curr_pt == pt_cse) curr_pt = pt_dir;
    else if (curr_pt == pt_dir) curr_pt = pt_normal;

    //Buraya bir akil ekleyecegim... su sekilde
    //Eger hizi degismisse 'c' veya 'd' paketi gonderecegim
    //eger degismemisse standart paket gonderecegim
    //belirli araliklarla da PHG paketi gonderip istasyonu tanitacagiz
    while(bitRead(PORTB,5)); //Wait for transmission to be completed

}

char* deg_to_nmea(float deg, boolean is_lat) {
  bool is_negative=0;
  if (deg < 0) is_negative=1;
  deg = abs(deg);
  float minute = (deg - (int) deg) * 60;
  sprintf(conv_buf,"%03d%02d.%02d ",(int)deg,(int)minute,(int)(100*minute)%100);
  //conv_buf[9] = '\0';
  if (is_lat) {
    if (is_negative) { conv_buf[8]='S';}
    else conv_buf[8]='N';
    //DEBUG_PORT.println(conv_buf+1);
    return conv_buf+1;
    }
  else {
    if (is_negative) {conv_buf[8]='W';}
    else conv_buf[8]='E';
    //DEBUG_PORT.println(conv_buf);
    return conv_buf;
    }
}

/*
 * Config Struct ina uygun sayida veriyi sirayla EEPROM'dan okuyup 
 * bu struct a uygun degiskenin icine atiyoruz
 */
void eepromOku() {
  for (unsigned int i=0; i<sizeof(Ayarlar); i++) {
    *((char*)&Ayarlar + i) = EEPROM.read(i);
  }
  /*Cagri isareti dogru ise hepsinin dogru oldugunu kabul ediyoruz*/
  unsigned int iCheckSum = 0;
  for (int i=0; i<7; i++) {
    iCheckSum += Ayarlar.APRS_CagriIsareti[i];
  }
  if (iCheckSum != Ayarlar.CheckSum)  VarsayilanAyarlar();
  DEBUG_PORT.println(F("EEPROM'dan okuma tamamlandi"));
}

/*
 * CONFIG tipinde bir Struct i EEPROM a yaziyoruz
 */
void eepromaYaz() {
  for (unsigned int i=0; i<sizeof(Ayarlar); i++) {
    EEPROM.write(i, *((char*)&Ayarlar + i));
  }
  DEBUG_PORT.println("Eeproma yazildi");
}

/*
 * Print configuration details to serial port
 */
void konfigurasyonYazdir()
{
  /*
  DEBUG_PORT.println("Mevcut Konfigurasyon Bilgileri");
  DEBUG_PORT.println("------------------------------");
  */
  DEBUG_PORT.print(F("Cagri Isareti : "));  
  DEBUG_PORT.println(Ayarlar.APRS_CagriIsareti);
  DEBUG_PORT.print(F("         SSID : -")); 
  DEBUG_PORT.println(Ayarlar.APRS_CagriIsaretiSSID);
  DEBUG_PORT.print(F("        Hedef : "));  
  DEBUG_PORT.println(Ayarlar.APRS_Destination);
  DEBUG_PORT.print(F("   Hedef SSID : -")); 
  DEBUG_PORT.println(Ayarlar.APRS_DestinationSSID);  
  DEBUG_PORT.print(F("        Path1 : "));  
  DEBUG_PORT.println(Ayarlar.APRS_Path1);
  DEBUG_PORT.print(F("   Path1 SSID : -")); 
  DEBUG_PORT.println(Ayarlar.APRS_Path1SSID);
  DEBUG_PORT.print(F("        Path2 : "));  
  DEBUG_PORT.println(Ayarlar.APRS_Path2);
  DEBUG_PORT.print(F("   Path2 SSID : -")); 
  DEBUG_PORT.println(Ayarlar.APRS_Path2SSID);
  DEBUG_PORT.print(F("       Sembol : "));  
  DEBUG_PORT.println(Ayarlar.APRS_Sembolu);
  DEBUG_PORT.print(F("  Sembol Tipi : "));  
  DEBUG_PORT.println(Ayarlar.APRS_SembolTabi);
  DEBUG_PORT.print(F("  Beacon Tipi : "));  
  DEBUG_PORT.println(Ayarlar.APRS_BeaconTipi); //0=sure beklemeli, 1=Smart Beacon
  DEBUG_PORT.print(F("Beacon Suresi : "));  
  DEBUG_PORT.println(Ayarlar.APRS_BeaconSuresi);
  DEBUG_PORT.print(F("     GPS Hizi : "));  
  DEBUG_PORT.println(Ayarlar.APRS_GPSSeriHizi);    
  DEBUG_PORT.print(F("        Mesaj : "));  
  DEBUG_PORT.println(Ayarlar.APRS_Mesaj);
  DEBUG_PORT.print(F("  GPS Var/Yok : "));  
  DEBUG_PORT.println(Ayarlar.gps_varyok);
  DEBUG_PORT.print(F("Koor.Latitude : "));  
  DEBUG_PORT.println(Ayarlar.latitude);
  DEBUG_PORT.print(F("Koor.Longitude: "));  
  DEBUG_PORT.println(Ayarlar.longitude);
  DEBUG_PORT.print(F("Koor.Altitude : "));  
  DEBUG_PORT.println(Ayarlar.altitude);
  DEBUG_PORT.print(F("   PGH(Power) : "));  
  DEBUG_PORT.println(Ayarlar.power);
  DEBUG_PORT.print(F("    PGH(Gain) : "));  
  DEBUG_PORT.println(Ayarlar.gain);
  DEBUG_PORT.print(F("  PGH(Height) : "));  
  DEBUG_PORT.println(Ayarlar.height);
  DEBUG_PORT.print(F(" PGH(Direct.) : "));  
  DEBUG_PORT.println(Ayarlar.directivity);
  DEBUG_PORT.print(F("Kontrol (CRC) : "));  
  DEBUG_PORT.println(Ayarlar.CheckSum);   

}

void VarsayilanAyarlar() {
  strcpy(Ayarlar.APRS_CagriIsareti, "iZCi01"); 
  Ayarlar.APRS_CagriIsaretiSSID = '9';
  strcpy(Ayarlar.APRS_Destination, "APiZCi");
  Ayarlar.APRS_DestinationSSID = '0';
  strcpy(Ayarlar.APRS_Path1, "WIDE1 ");
  Ayarlar.APRS_Path1SSID = '1';
  strcpy(Ayarlar.APRS_Path2, "WIDE2 ");
  Ayarlar.APRS_Path2SSID = '1';
  Ayarlar.APRS_Sembolu = '>';
  Ayarlar.APRS_SembolTabi = '/';
  Ayarlar.APRS_BeaconTipi = 3;
  Ayarlar.APRS_BeaconSuresi = 1;
  strcpy(Ayarlar.APRS_Mesaj, "iZCi hymTR APRS Tracker");
  Ayarlar.APRS_GPSSeriHizi = 9600;
  Ayarlar.gps_varyok = 1;
  strcpy(Ayarlar.latitude, "3955.50N");
  strcpy(Ayarlar.longitude, "3250.22E");
  strcpy(Ayarlar.altitude, " 2400");
  Ayarlar.power = 1;
  Ayarlar.gain = 1;
  Ayarlar.height = 1;
  Ayarlar.directivity = 1;
  Ayarlar.CheckSum = 367;  //iZCi icin Checksum degeri
  eepromaYaz();
}

void KomutSatiriCalistir() {
  byte komut;

  DEBUG_PORT.println(F("hymTR Konfigurasyon Arayuzu"));
  DEBUG_PORT.print('#');
  delay(50);

  while (komut != 'Q') {
    //digitalWrite(13, !digitalRead(13)); //Gonderme yaptigimizda tracker i konsol modundan cikariyoruz
    delay(50);
    if (DEBUG_PORT.available()) {
      komut = DEBUG_PORT.read();

      if (komut == 'R') {
        eepromOku();    
        seriyeGonder();
      }

      if (komut == 'P') {
        konfigurasyonYazdir();    
      }

      if (komut == 'W') {
        DEBUG_PORT.println(F("Konfigurasyon kaydediliyor..."));
        delay(500);
        DEBUG_PORT.println(VERSIYON);
       konfigurasyonYazdir();
        if (seridenAl()) {
              eepromaYaz();
            } else {
          //DEBUG_PORT.println(F("hata  olustu..."));
        }
      }
      
      if (komut == 'D') {
        DEBUG_PORT.println(F("Varsayilan konfigurasyona donuluyor"));
        VarsayilanAyarlar();        
      }
      DEBUG_PORT.println('#');
    } //DEBUG_PORT.available
 } //komut != Q
 DEBUG_PORT.println(F("Konfigurasyon modundan cikiliyor"));
} //komutSatiriCalistir


/*
 * seri olarak okunan byte lari 0x09 veya 0x04 e kadar olanini geri dondurmek icin
 */
void parametreOku(char *szParam, int iMaxLen) {
  byte c;
  int iSize;
  unsigned long iMilliTimeout = millis() + 2000; 

  for (iSize=0; iSize<iMaxLen; iSize++) szParam[iSize] = 0x00; 
  iSize = 0;   

  while (millis() < iMilliTimeout) {

    if (DEBUG_PORT.available()) {
      c = DEBUG_PORT.read();

      if (c == 0x09 || c == 0x04) {
        DEBUG_PORT.println();
        return;
      }
      if (iSize < iMaxLen) {
        szParam[iSize] = c;
        iSize++;
      }
    }
  }

}

bool seridenAl() {
  char szParam[45]; //en uzun mesaajdan daha uzun 45>41
  unsigned long iMilliTimeout = millis() + 10000;    
  while (millis() < iMilliTimeout) {
  while (!DEBUG_PORT.available()) { } //veri gelmesini bekle
    if (DEBUG_PORT.read() == 0x01) {
      parametreOku(szParam, sizeof(szParam));
      if (strcmp(szParam, VERSIYON) != 0) {
        DEBUG_PORT.println(szParam);
          DEBUG_PORT.println(F("E99 Versiyonlar uyumsuz..."));
        return false;
      }
    
      parametreOku(szParam, sizeof(Ayarlar.APRS_CagriIsareti));    //CagriIsareti
      strcpy(Ayarlar.APRS_CagriIsareti, szParam);
      parametreOku(szParam, 1);    //CagriIsareti SSID
      Ayarlar.APRS_CagriIsaretiSSID = szParam[0];


      parametreOku(szParam, sizeof(Ayarlar.APRS_Destination));    //Destination
      //strcpy(Ayarlar.APRS_Destination, szParam);
      parametreOku(szParam, 1);    //SSID
      //Ayarlar.APRS_DestinationSSID = szParam[0];

      parametreOku(szParam, sizeof(Ayarlar.APRS_Path1));    //Path1
      strcpy(Ayarlar.APRS_Path1, szParam);
      parametreOku(szParam, 1);    //SSID
      Ayarlar.APRS_Path1SSID = szParam[0];

      parametreOku(szParam, sizeof(Ayarlar.APRS_Path2));    //Path2
      strcpy(Ayarlar.APRS_Path2, szParam);
      parametreOku(szParam, 1);    //SSID
      Ayarlar.APRS_Path2SSID = szParam[0];

      //Symbol/Tab
      parametreOku(szParam, 1);
      Ayarlar.APRS_Sembolu = szParam[0];
      parametreOku(szParam, 1);
      Ayarlar.APRS_SembolTabi = szParam[0];

      //BeaconTipi
      parametreOku(szParam, sizeof(szParam));
      Ayarlar.APRS_BeaconTipi = atoi(szParam);

      //Beacon Suresi
      parametreOku(szParam, sizeof(szParam));
      Ayarlar.APRS_BeaconSuresi = atoi(szParam);

      //GPS Seri Hizi
      parametreOku(szParam, sizeof(szParam));
      Ayarlar.APRS_GPSSeriHizi = atoi(szParam);

      //Status Message
      parametreOku(szParam, sizeof(szParam));
      strcpy(Ayarlar.APRS_Mesaj, szParam);

      //GPS Var/Yok
      parametreOku(szParam, sizeof(szParam));
      Ayarlar.gps_varyok = atoi(szParam);    

      //Latitude
      parametreOku(szParam, sizeof(szParam));
      strcpy(Ayarlar.latitude,szParam);

      //Longitude
      parametreOku(szParam, sizeof(szParam));
      strcpy(Ayarlar.longitude,szParam);

      //Altitude
      parametreOku(szParam, sizeof(szParam));
      strcpy(Ayarlar.altitude,szParam);

      //parametreOku(szParam, sizeof(szParam));
      //Ayarlar.power = atoi(szParam);    

      //parametreOku(szParam, sizeof(szParam));
      //Ayarlar.gain = atoi(szParam);    

      //parametreOku(szParam, sizeof(szParam));
      //Ayarlar.height = atoi(szParam);    

      //parametreOku(szParam, sizeof(szParam));
      //Ayarlar.directivity = atoi(szParam);    

      unsigned int iCheckSum = 0;
      for (int i=0; i<7; i++) {
        iCheckSum += Ayarlar.APRS_CagriIsareti[i];
      }
      Ayarlar.CheckSum = iCheckSum;
      return true;    //OKuma tamamlandi
    } // read 0x01
  } //millis
  return false;

}

/*
 * Elimizdeki CONFIG degiskenini byte byte PC'ye gonderiyoruz
 */
void seriyeGonder() {
        DEBUG_PORT.print(F("{"));    //JSON Baslangici
        DEBUG_PORT.print(F("'V':'"));
        DEBUG_PORT.print(VERSIYON);
        DEBUG_PORT.print(F("','CagriIsareti':'"));
        DEBUG_PORT.print(Ayarlar.APRS_CagriIsareti);
        DEBUG_PORT.print(F("','CagriIsaretiSSID':"));
        DEBUG_PORT.print(Ayarlar.APRS_CagriIsaretiSSID);
        DEBUG_PORT.print(F(",'Destination':'"));
        DEBUG_PORT.print(Ayarlar.APRS_Destination);
        DEBUG_PORT.print(F("','DestinationSSID':"));
        DEBUG_PORT.print(Ayarlar.APRS_DestinationSSID);
        DEBUG_PORT.print(F(",'Path1':'"));
        DEBUG_PORT.print(Ayarlar.APRS_Path1);
        DEBUG_PORT.print(F("','Path1SSID':"));
        DEBUG_PORT.print(Ayarlar.APRS_Path1SSID);
        DEBUG_PORT.print(F(",'Path2':'"));
        DEBUG_PORT.print(Ayarlar.APRS_Path2);
        DEBUG_PORT.print(F("','Path2SSID':"));
        DEBUG_PORT.print(Ayarlar.APRS_Path2SSID);
        //Symbol
        DEBUG_PORT.print(F(",'Sembol':'"));
        DEBUG_PORT.print(Ayarlar.APRS_Sembolu);
        DEBUG_PORT.print(F("','SembolTabi':'"));
        DEBUG_PORT.print(Ayarlar.APRS_SembolTabi);
        //Beacon Type
        DEBUG_PORT.print(F("','BeaconTipi':"));
        DEBUG_PORT.print(Ayarlar.APRS_BeaconTipi, DEC);
        DEBUG_PORT.print(F(",'BeaconSuresi':"));
        //Beacon - Simple Delay
        DEBUG_PORT.print(Ayarlar.APRS_BeaconSuresi, DEC);
        //Status Message
        DEBUG_PORT.print(F(",'Mesaj':'"));
        DEBUG_PORT.print(Ayarlar.APRS_Mesaj);
        //GPS DEBUG_PORT Data
        DEBUG_PORT.print(F("','GPSHizi':"));
        DEBUG_PORT.print(Ayarlar.APRS_GPSSeriHizi, DEC);      
        DEBUG_PORT.print(F(",'GPSvar_yok':"));
        DEBUG_PORT.print(Ayarlar.gps_varyok, DEC);      
        DEBUG_PORT.print(F(",'latitude':'"));
        DEBUG_PORT.print(Ayarlar.latitude);      
        DEBUG_PORT.print(F("','longitude':'"));
        DEBUG_PORT.print(Ayarlar.longitude);      
        DEBUG_PORT.print(F("','altitude':'"));
        DEBUG_PORT.print(Ayarlar.altitude);      
        DEBUG_PORT.print(F("','power':"));
        DEBUG_PORT.print(Ayarlar.power,DEC);      
        DEBUG_PORT.print(F(",'gain':"));
        DEBUG_PORT.print(Ayarlar.gain,DEC);      
        DEBUG_PORT.print(F(",'height':"));
        DEBUG_PORT.print(Ayarlar.height,DEC);      
        DEBUG_PORT.print(F(",'directivity':"));
        DEBUG_PORT.print(Ayarlar.directivity,DEC);      
        DEBUG_PORT.print(F("}")); //JSON SONU
}


int getGpsData(boolean *newDataLoc)
{
 while (gps.available( gpsPort )) {
    fix = gps.read();
    //DEBUG_PORT.println(fix.satellites);
    //DEBUG_PORT.println(fix.status);
    //DEBUG_PORT.println(fix.dateTime);
    //DEBUG_PORT.println("--------------------------");
    if (fix.valid.location && fix.valid.time && fix.valid.altitude) {
      *newDataLoc = true;
      //DEBUG_PORT.print("GOT FIXXX");
      return fix.dateTime.minutes*60+fix.dateTime.seconds;
    }
  }
return -1; 
}


//-----------------
//  Print utilities
/*
static void repeat( char c, int8_t len )
{
  for (int8_t i=0; i<len; i++)
    DEBUG_PORT.write( c );
}
static void printInvalid( int8_t len )
{
  DEBUG_PORT.write( ' ' );
  repeat( '*', abs(len)-1 );
}

static void print( float val, bool valid, int8_t len, int8_t prec )
{
  if (!valid) {
    printInvalid( len );
  } else {
    char s[16];
    dtostrf( val, len, prec, s );
    DEBUG_PORT.print( s );
  }
}
static void print( int32_t val, bool valid, int8_t len )
{
  if (!valid) {
    printInvalid( len );
  } else {
    char s[16];
    ltoa( val, s, 10 );
    repeat( ' ', len - strlen(s) );
    DEBUG_PORT.print( s );
  }
}

static void print( const __FlashStringHelper *str, bool valid, int8_t len )
{
  if (!valid) {
    printInvalid( len );
  } else {
    int slen = strlen_P( (const char *) str );
    repeat( ' ', len-slen );
    DEBUG_PORT.print( str );
  }
}

static void print( const NeoGPS::time_t & dt, bool valid, int8_t len )
{
  if (!valid) {
    printInvalid( len );
  } else {
    DEBUG_PORT.write( ' ' );
    Serial << dt; 
  }
}
*/

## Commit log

2020-01-18 GPS okuma ve Seri port rutinleri degistirildi
    gps okumak icin nmae NeoGPS kutuphanesine gecildi
    seri port icin neoSWserial kutuphanesi ve interrupt yapisina gecildi
2020-02-09 callsign length problem solved
    [hymTR.ino]
2020-03-15 Hardware eklendi
    [hymTracker.kicad_pcb, hymTracker.sch]
2020-03-15 sema cizildi
    [hymTracker.sch]
2020-03-15 pcb ye hazir
    [hymTracker.sch]
2020-03-15 pcb lib
2020-03-16 PCD cizimi tamamlandi
    [hymTracker.kicad_pcb, hymTracker.sch]
2020-03-16 PCB logo
    [hymTracker.kicad_pcb]
2020-03-17 yeni 3d elemanlar
    [hymTracker.kicad_pcb]
2020-03-17 yeni 3d elemanlar 2
    [hymTracker.kicad_pcb]
2020-03-17 resimler guncellendi
    [hymTracker.kicad_pcb]
2020-04-17 Panel eklentisi
    [hymTracker_Panel.kicad_pcb]
2020-04-18 panel.. callsign and RULER added
    [hymTracker.kicad_pcb, hymTracker_Panel.kicad_pcb]
2020-04-18 gerbers created
    [hymTracker_Panel-B_Cu.gbr, hymTracker_Panel-B_Mask.gbr, hymTracker_Panel-B_Paste.gbr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]
2020-08-06 R805->R1206 (small)
    [hymTracker.kicad_pcb]
2020-08-10 son degisiklikler
    [hymTracker.kicad_pcb]
2020-08-17 gps ters cevrildi
    [hymTracker.kicad_pcb]
2020-08-17 gerber output
    [hymTracker-B_Cu.gbr, hymTracker-B_Mask.gbr, hymTracker-B_Paste.gbr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]
2020-09-03 dual version
    [hymTR_dual-B_Cu.gbr, hymTR_dual-B_Mask.gbr, hymTR_dual-B_Paste.gbr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]
